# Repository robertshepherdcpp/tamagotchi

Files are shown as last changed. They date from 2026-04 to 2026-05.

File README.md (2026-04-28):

# tamagotchi
luna-tamagotchi
my second project for fallout

**what the project is:**
- a custom tamagotchi consisting of a pcb designed in kiad and a case designed in the CAD software Fusion360
what the tamagotchi consists of:
- - a 3d case + lid
  - the pcb which consists of: XIAO-ESP32-C6, buzzer, rotary encoder, 4 buttons, and a 0.96" screen.

**why i chose to make with project (the inspiration/motivation):**
- as i am still new to hardware, i thought having a tutorial as a fallback for if i got stuck would be useful (avoid endless rabbit holes hhh). also i remember using a tamagotchi when i was younger and thought it was pretty cool
- so i decided to make a tamagotchi but to personalize it, so i made it of my friend luna.
- therefore as the firmware i planned to make it have many of the same interests/personality traits as my friend
- my mum had one of these when she was younger, and I thought it would be cool to make my own version and show it to her.

**how to use my project**
- first print off etc. the pcb and case. many different providers to do this.
- then to load the firmware (found in this respository), you can:
```
download the arduino IDE, install all the relevant libraries: Adafruit SSD1306 (by Adafruit), Adafruit GFX Library (by Adafruit). then
load up the xiao-esp32-c6 board. plug the project into your computer via usb, and press port on the arduino guide. as this project doesnt have a battery built
in, in order for this project to work it has to have a usb connected to it at all times.
for more help you can refer to these two guides:
https://fallout.hackclub.com/docs/guided-projects/tamagotchi-firmware
https://wiki.seeedstudio.com/xiao_esp32c6_getting_started/
```

**how the project works**
- the project is mainly just a tamogatchi with a few little changes.
- the pet has different characteristics, hunger, happiness, energy, age, intelligence
- there are 4 main states: `nap [SJ]`, `feed luosifen [LSF]`, `climb a mountain [CLMB]`, `wildcard [WLDCRD]`.
- nap: energy increases by 15 points, intelligence increases by 10 points.
- feed: hunger increases by 10 points (means it is getting less hungry), energy increases by 5 points
- play: happiness increases by 10 points, energy decreases by 5 points
- wildcard: this is where the rotary encoder comes into play, you select a random orientation on the tamogotchi which corresponds to a number
0-19 inclusive. a random number is then selected, if you pick that number, the one below it or above it, the pets happiness is doubled! however if you
dont guess correctly, its decreased by 15%!! are you willing to risk your pets happiness?
- all values apart from age are capped in the ranges 1 to 100.
- the aim to get all values as high as possible.
- this is all done behind the scenes with the pcb, controlled by the XIAO-ESP32-C6.

**how to use it?**
- after setting up the project (with the PCB and Case etc. all set up):
- this tamagotchi is your pet, you can feed it (luosifen), let it play (climb mountains), let it take a nap, and you can also go to a section called the wildcard
- this is where you pick a random number between 1 and 18 and if you get the number or one of the adjacent numbers, your pets happiness doubles! however if not the happiness is decreased by 15%.
- your ultimate goal is to keep your pet happy, healthy etc. by keeping the 4 stats variables high (intelligence, hunger, energy and happiness)

here are some images of the project:




(there are a few components missing in this image because the STEP files for them didnt load, however shouldnt have any effect when it comes to
the actual PCB fabrication.)



estimated costs (via uploading gerber files to jlcpcb):

[link](https://cart.jlcpcb.com/quote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)

my zine:


The BOM (available in BOM.csv in this github repo):
aliexpress [link](https://www.aliexpress.com/p/shoppingcart/index.html?spm=a2g0o.tm1000056364.header.1.52471bf5lQ3z1L)

Total Cost: $27.44

the whole building process was documented on my youtube channel [here](https://www.youtube.com/@robertshepherdcpp)

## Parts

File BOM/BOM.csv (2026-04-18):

Item | Description | Quantity | Unit Price ($) | Total Price ($) | URL | Running Total ($ with Tax)
XIAO ESP32 C3 | MCU | 1 | $4.34 | $4.34 | https://www.aliexpress.us/item/3256808605622611.html | $4.34
Display | s | 1 | $2.46 | $2.46 | https://www.aliexpress.us/item/3256807544901434.html | $6.80
Headers | Headers | 1 | $1.57 | $1.57 | https://www.aliexpress.us/item/3256811506646304.html | $8.37
Buzzer | 12*9.5mm | 1 | $2.23 | $2.23 | https://www.aliexpress.us/item/3256810135642750.html | $10.60
Button | 4.5X4.5MM Button | 1 | $2.01 | $2.01 | https://www.aliexpress.us/item/3256806953793236.html | $12.61
Threaded Inserts | M3X4X5 | 1 | $2.47 | $2.47 | https://www.aliexpress.us/item/3256811754262338.html | $15.08
Screws | M3, 10mm | 1 | $1.94 | $1.94 | https://www.aliexpress.com/p/shoppingcart/index.html?spm=a2g0o.tm1000056364.header.1.52471bf5lQ3z1L | $17.02
Rotary Encoder EC11 | "20mm" | 1 | $3.12 | $3.12 | https://alishort.com/0M4I1 | $20.14
Shipping | Aliexpress | 1 | $0 | $0 | https://www.aliexpress.us/ | $20.14
PCB | JLCPCB | 1 | $4 | $4 | https://jlcpcb.com/ | $24.14
Shipping | JLCPCB | 1 | $3.30 | $3.30 | https://jlcpcb.com/ | $27.44

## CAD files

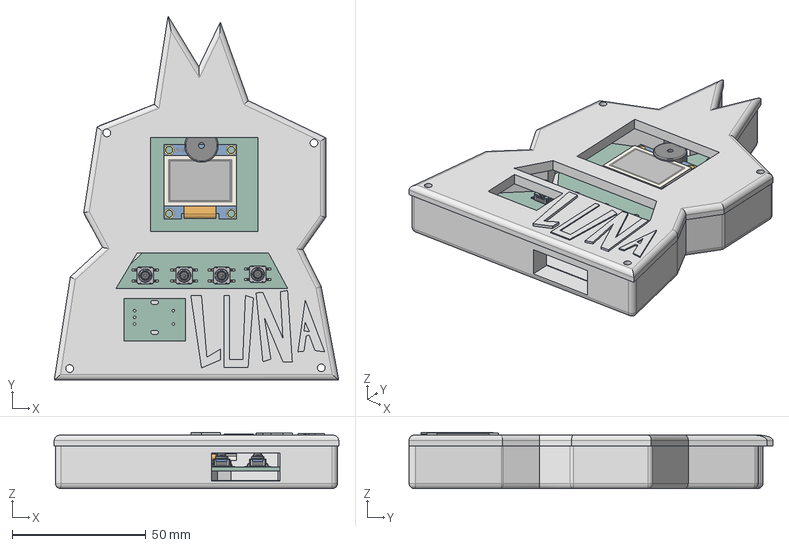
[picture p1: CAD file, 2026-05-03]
CAD/luna_2.step
106.3 x 135.9 x 21.0 mm
OLED-TH_L27.8-W27.2-P2.54_C9900033791
SW_Push_1P1T_NO_CK_KSC6xxG x 4
BUZ-TH_BD12.5-H7.0-P6.5
luna_PCB

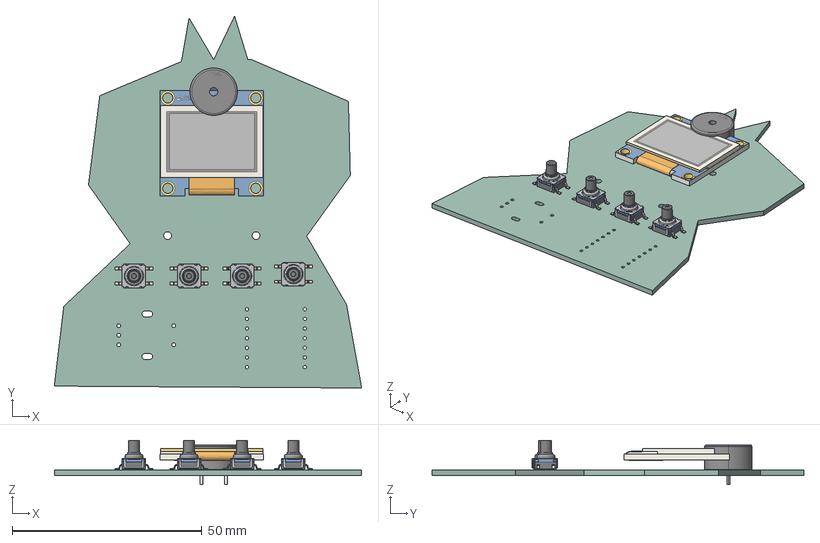
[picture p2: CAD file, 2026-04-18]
PCB/luna.step
81.0 x 98.0 x 11.7 mm
OLED-TH_L27.8-W27.2-P2.54_C9900033791
SW_Push_1P1T_NO_CK_KSC6xxG x 4
BUZ-TH_BD12.5-H7.0-P6.5
luna_PCB

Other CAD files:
CAD/luna_2.f3d

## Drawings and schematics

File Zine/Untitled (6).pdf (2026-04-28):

l

## a tamagotchi

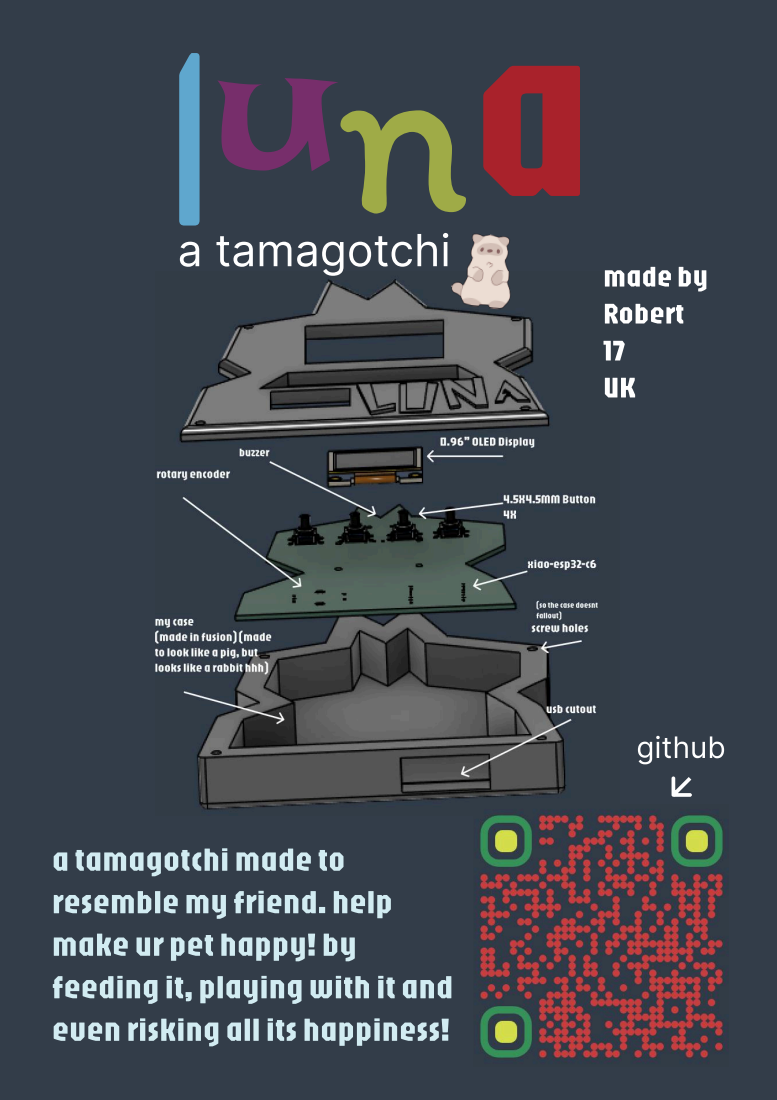
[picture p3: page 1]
una; made by Robert 17 UK; github

a tamagotchi made to
resemble my friend. help
make ur pet happy! by
feeding it, playing with it and
even risking all its happiness!

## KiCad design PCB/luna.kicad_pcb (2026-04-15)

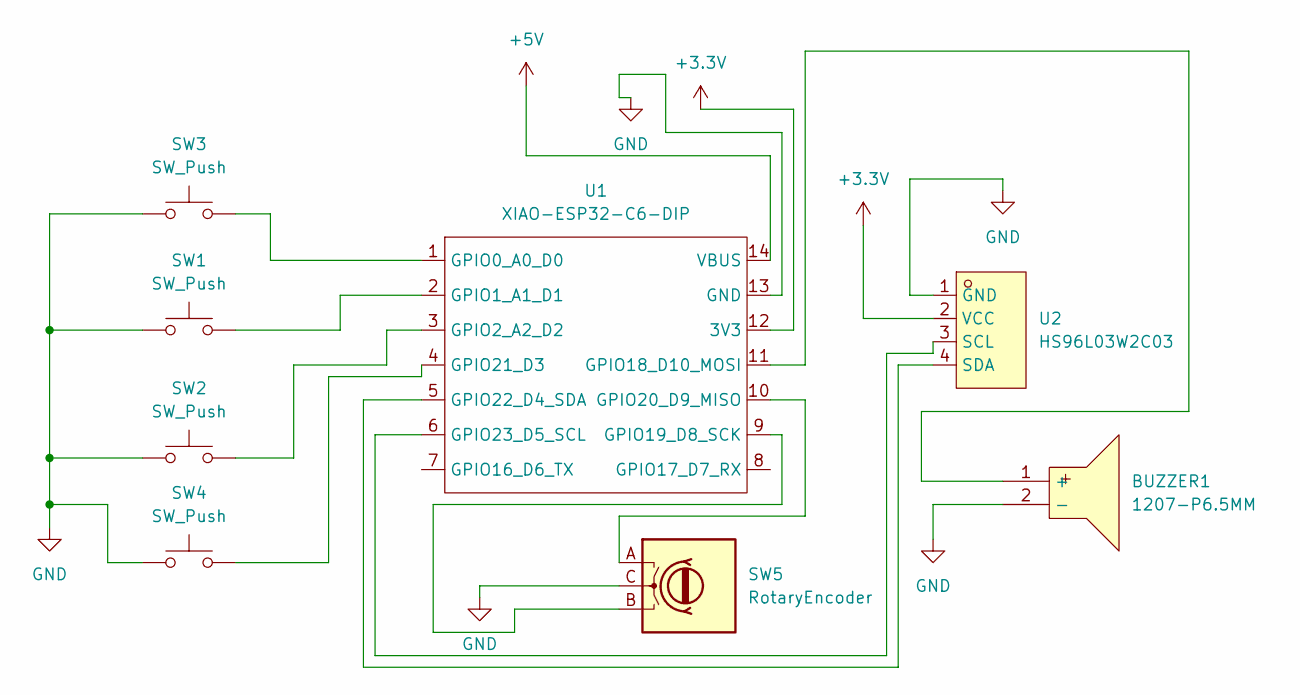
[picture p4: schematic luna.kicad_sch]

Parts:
BUZZER1: 1207-P6.5MM; BUZ-TH_BD12.5-P6.50-D1.4; MPN 1207-P6.5MM; LCSC Part C49246964
SW1, SW2, SW3, SW4: SW_Push; SW_Push_1P1T_NO_CK_KSC6xxG
SW5: RotaryEncoder; RotaryEncoder_Alps_EC11E-Switch_Vertical_H20mm
U1: XIAO-ESP32-C6-DIP
U2: HS96L03W2C03; OLED-TH_L27.8-W27.2-P2.54_C9900033791; MPN HS96L03W2C03; LCSC Part C5248080

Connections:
+3.3V: U1.12 (3V3), U2.2 (VCC)
+5V: U1.14 (VBUS)
GND: BUZZER1.2 (-), SW1.1, SW2.1, SW3.1, SW4.1, SW5.C, U1.13 (GND), U2.1 (GND)
unnamed: BUZZER1.1 (+), U1.11 (GPIO18_D10_MOSI)
unnamed: SW3.2, U1.1 (GPIO0_A0_D0)
unnamed: SW1.2, U1.2 (GPIO1_A1_D1)
unnamed: SW2.2, U1.3 (GPIO2_A2_D2)
unnamed: SW5.B, U1.9 (GPIO19_D8_SCK)
unnamed: SW5.A, U1.10 (GPIO20_D9_MISO)
unnamed: SW4.2, U1.4 (GPIO21_D3)
unnamed: U1.5 (GPIO22_D4_SDA), U2.4 (SDA)
unnamed: U1.6 (GPIO23_D5_SCL), U2.3 (SCL)

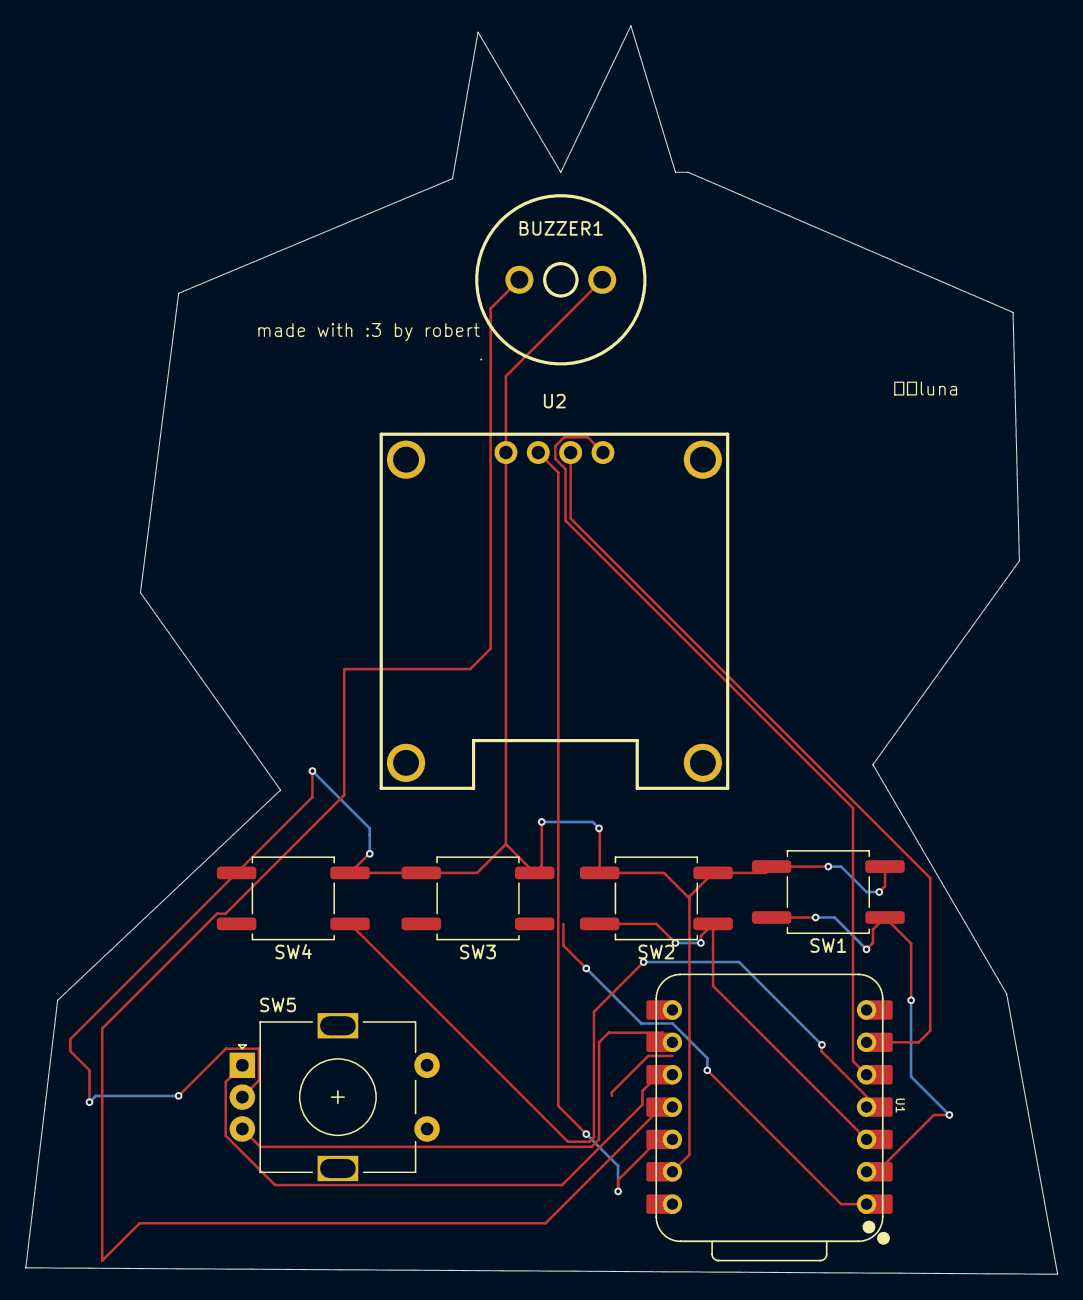
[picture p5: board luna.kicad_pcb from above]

Board: 2 copper layers, 81.0 x 98.0 mm, 8 parts (0 on the bottom side), 11 nets.

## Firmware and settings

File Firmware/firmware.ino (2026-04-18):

/*
summary of game logic:
plan for the different components
button:
1. Feed luosifen = feed (hunger)
2. Climb mountain = play (happiness, and decrease energy)
3. Nap = sleep (energy increased, intelligence increased by 1)
4. study = NEW ONE (increase intelligence by 10)

also a new stat called intelligence

for the rotary encoder - after a random amount of time on the main screen, say 5 seconds, can be taken to a wild card,
where a random number is calculated from 1 to 20, if they get the number (they can select it using the buttons)
- if they get the number, the number bellow, the number or the number above then the score is doubled!
- otherwise the score is decreased by 15% (*0.85)


*/

// buttons
#define BTN1 0
#define BTN2 1
#define BTN3 2
#define BTN4 21

//OLED display
#define SDA_PIN 22
#define SCL_PIN 23

// buzzer
#define BZR 18

// rotary encoder
#define RE_A 20
#define RE_B 19

// includes, and setting up other stuff
#include <Wire.h>
#include <Adafruit_GFX.h>
#include <Adafruit_SSD1306.h>

#define SCREEN_WIDTH 128
#define SCREEN_HEIGHT 64
#define OLED_RESET -1

Adafruit_SSD1306 display(SCREEN_WIDTH, SCREEN_HEIGHT, &Wire, OLED_RESET);

#define BTN_LEFT D0    // EAT LUOSIFEN
#define BTN_MIDDLE D1  // CLIMB A MOUNTAIN
#define BTN_RIGHT D2   // NAP
#define BTN_DOWN D3    // STUDY

#define BUZZER_PIN D10

// im not sure if this is correct, but did the same for buttons, so probably the same.
#define RotaryEncoderA D9
#define RotaryEncoderB D8

struct Pet {
  int hunger;         // 0 to 100 (0 = starving, 100 = full)
  int happiness;      // 0 to 100 (0 = miserable, 100 = ecstatic)
  int energy;         // 0 to 100 (0 = exhausted, 100 = fully rested)
  unsigned long age;  // total seconds the pet has been alive
  int intelligence;   // 0 to 100 (0 = dumb, 100 = mega brain)
};

// globals

Pet pet{};

int prev_CLK_state;  // checking if has changed, when using the rotary encoder
int count;           // measured of the rotary encoder. 1-20 (360 degrees and 18 degree increments)
int lastValue{};

enum Screen {
  SCREEN_MAIN,
  SCREEN_FEED,     // eat luosifen
  SCREEN_PLAY,     // climb mountain
  SCREEN_SLEEP,    // nap
  SCREEN_STUDY,    // study
  SCREEN_WILDCARD  // pick a random number between 1 and 4 if right .... (this is done if the user stays on the main screen for 10 seconds)
};

Screen currentScreen = SCREEN_MAIN;

void setup() {
  pinMode(BTN_LEFT, INPUT_PULLUP);
  pinMode(BTN_MIDDLE, INPUT_PULLUP);
  pinMode(BTN_RIGHT, INPUT_PULLUP);
  pinMode(BTN_DOWN, INPUT_PULLUP);

  pinMode(BUZZER_PIN, OUTPUT);

  // TODO: also do for the rotary encoder, but probably wont be the same, do some research....
  pinMode(RotaryEncoderA, INPUT);  // seems like these dont need a pullup, but idk...
  pinMode(RotaryEncoderB, INPUT);

  prev_CLK_state = digitalRead(RotaryEncoderA);

  display.begin(SSD1306_SWITCHCAPVCC, 0x3C);
  display.clearDisplay();
  display.setTextSize(1);
  display.setTextColor(SSD1306_WHITE);
  display.setCursor(0, 0);
  display.println("LUNA Init...");
  display.display();
  delay(1000);

  pet.hunger = 80;
  pet.happiness = 80;
  pet.energy = 80;
  pet.age = 0;
}

unsigned long lastUpdate = 0;

void updatePet() {
  if (millis() - lastUpdate > 5000) {  // every 5 seconds
    pet.hunger--;
    pet.happiness--;
    pet.energy--;

    if (pet.hunger < 0) pet.hunger = 0;
    if (pet.happiness < 0) pet.happiness = 0;
    if (pet.energy < 0) pet.energy = 0;

    pet.age += 5;
    lastUpdate = millis();
  }
}

unsigned long lastButtonPress = 0;

void checkButtons() {
  if (millis() - lastButtonPress < 200) return;  // debounce: ignore presses within 200ms

  if (digitalRead(BTN_LEFT) == LOW) {
    currentScreen = SCREEN_FEED;
    tone(BUZZER_PIN, 1000, 50);
    lastButtonPress = millis();
  } else if (digitalRead(BTN_MIDDLE) == LOW) {
    currentScreen = SCREEN_PLAY;
    tone(BUZZER_PIN, 1200, 50);
    lastButtonPress = millis();
  } else if (digitalRead(BTN_RIGHT) == LOW) {
    currentScreen = SCREEN_SLEEP;
    tone(BUZZER_PIN, 800, 50);
    lastButtonPress = millis();
  } else if (digitalRead(BTN_DOWN) == LOW) {  //i.e. its clicked
    currentScreen = SCREEN_WILDCARD;
    tone(BUZZER_PIN, 1400, 75);
    lastButtonPress = millis();
  }
}

void handleScreenLogic() {
  switch (currentScreen) {

    case SCREEN_FEED:
      pet.hunger += 10;
      pet.energy += 5;
      if (pet.energy > 100) pet.energy = 100;
      if (pet.hunger > 100) pet.hunger = 100;
      currentScreen = SCREEN_MAIN;
      break;

    case SCREEN_PLAY:
      pet.happiness += 10;
      pet.energy -= 5;
      if (pet.happiness > 100) pet.happiness = 100;
      if (pet.energy < 0) pet.energy = 0;
      currentScreen = SCREEN_MAIN;
      break;

    case SCREEN_SLEEP:
      pet.energy += 15;
      pet.intelligence += 10;
      if (pet.intelligence > 100) pet.intelligence = 100;
      if (pet.energy > 100) pet.energy = 100;
      currentScreen = SCREEN_MAIN;
      break;

    case SCREEN_WILDCARD:
    {
      // here we are going to check for the rotary encoder getting moved
      // CLK = A
      // DT = B

      // to check if there has been any change.
      lastValue = count;

      auto currentStateCLK = digitalRead(RotaryEncoderA);

      auto start = millis();

      while (millis() - start < 3000) {
        if (currentStateCLK != prev_CLK_state) {
          // Read the state of DT to determine rotation direction
          if (digitalRead(RotaryEncoderB) != currentStateCLK) {
            if (count == 19) {
              count = -1;  // which then gets incremented to 0.
            }
            count++;  // Clockwise rotation
          } else {
            if (count == 0) {
              count = 20;  // which then gets decremented to 19.
            }
            count--;  // Counterclockwise rotation
          }
        }
        prev_CLK_state = currentStateCLK;
      }

      // now we have got the count, we need to find a random number.
      int num = int(random(0, 20));
      // check if it is round about.
      if (count == (num - 1) || count == (num) || count == (num + 1)) {
        pet.happiness *= 2;
        if (pet.happiness > 100) {
          pet.happiness = 100;
        }
      } else {
        // they didnt get it, decrease by 15%
        pet.happiness = int(pet.happiness * 0.85);
      }
      currentScreen = SCREEN_MAIN;
    }
    break;

    case SCREEN_MAIN:
      break;  // do nothing, just display stats
  }
}

const unsigned char PROGMEM petHappy[] = {
  0b00000000, 0b00000000,
  0b00000001, 0b11110000,
  0b00000011, 0b00011000,
  0b00000110, 0b00001000,
  0b00001100, 0b00001000,
  0b00011001, 0b00100100,
  0b00010000, 0b00000100,
  0b00110000, 0b00000100,
  0b00100010, 0b00100100,
  0b00100011, 0b01100100,
  0b00100011, 0b11000100,
  0b00110000, 0b00001100,
  0b00011000, 0b00001000,
  0b00001100, 0b00011000,
  0b00000111, 0b11110000,
  0b00000000, 0b00000000
};

// Usage:
// display.drawBitmap(x, y, sprite, 16, 16, SSD1306_WHITE);

// Example: Sad face (any stat below 30)
const unsigned char PROGMEM petSad[] = {
  0b00000000, 0b00000000,
  0b00000001, 0b11110000,
  0b00000011, 0b00011000,
  0b00000110, 0b00001000,
  0b00001100, 0b00001000,
  0b00011001, 0b00100100,
  0b00010000, 0b00000100,
  0b00110000, 0b00000100,
  0b00100011, 0b11000100,
  0b00100110, 0b01100100,
  0b00100100, 0b00100100,
  0b00110000, 0b00001100,
  0b00011000, 0b00001000,
  0b00001100, 0b00011000,
  0b00000111, 0b11110000,
  0b00000000, 0b00000000
};

// Usage:
// display.drawBitmap(x, y, sprite, 16, 16, SSD1306_WHITE);

const unsigned char PROGMEM petNeutral[] = {
  0b00000000, 0b00000000,
  0b00000001, 0b11110000,
  0b00000011, 0b00011000,
  0b00000110, 0b00001000,
  0b00001100, 0b00001000,
  0b00011001, 0b00100100,
  0b00010000, 0b00000100,
  0b00110000, 0b00000100,
  0b00100000, 0b00000100,
  0b00100111, 0b11100100,
  0b00100000, 0b00000100,
  0b00110000, 0b00001100,
  0b00011000, 0b00001000,
  0b00001100, 0b00011000,
  0b00000111, 0b11110000,
  0b00000000, 0b00000000
};

//pet sleep
const unsigned char PROGMEM sprite[] = {
  0b00000000, 0b00000000,
  0b00000001, 0b11110000,
  0b00000011, 0b00011000,
  0b00000110, 0b00001000,
  0b00001100, 0b00001000,
  0b00011000, 0b00000100,
  0b00010000, 0b00000100,
  0b00110000, 0b00000100,
  0b00100000, 0b00000100,
  0b00100011, 0b11100100,
  0b00100000, 0b00000100,
  0b00110000, 0b00001100,
  0b00011000, 0b00001000,
  0b00001100, 0b00011000,
  0b00000111, 0b11110000,
  0b00000000, 0b00000000
};

// Usage:
// display.drawBitmap(x, y, sprite, 16, 16, SSD1306_WHITE);

void render() {
  display.clearDisplay();

  // Choose the right sprite based on pet stats
  const unsigned char* sprite;
  if (pet.hunger < 30 || pet.happiness < 30 || pet.energy < 30) {
    sprite = petSad;
  } else if (pet.hunger > 50 && pet.happiness > 50 && pet.energy > 50) {
    sprite = petHappy;
  } else {
    sprite = petNeutral;
  }

  // Draw the pet sprite (centered horizontally, near the top)
  display.drawBitmap(56, 2, sprite, 16, 16, SSD1306_WHITE);

  // Draw stat bars below the pet
  display.setTextSize(1);

  display.setCursor(0, 24);
  display.print("HUN ");
  drawBar(24, 24, pet.hunger);

  display.setCursor(0, 30);
  display.print("HAP ");
  drawBar(24, 30, pet.happiness);

  display.setCursor(0, 36);
  display.print("ENG ");
  drawBar(24, 36, pet.energy);

  display.setCursor(0, 42);
  display.print("INTG ");
  drawBar(24, 42, pet.intelligence);

  // should we print out the age?
  Serial.println(pet.age);  // just print it out to the console for now.

  // Button labels at the bottom
  display.setCursor(0, 56);
  display.println("[LSF] [CLMB] [SJ] [WLDCRD]");

  display.display();
}

// Draws a stat bar: empty rectangle with a filled portion based on value (0 to 100)
void drawBar(int x, int y, int value) {
  int barWidth = 100;
  int barHeight = 6;
  int fillWidth = map(value, 0, 100, 0, barWidth);

  display.drawRect(x, y, barWidth, barHeight, SSD1306_WHITE);   // outline
  display.fillRect(x, y, fillWidth, barHeight, SSD1306_WHITE);  // filled portion
}

void loop() {
  checkButtons();       // 1. Read input
  updatePet();          // 2. Update state over time
  handleScreenLogic();  // 3. Process actions
  render();             // 4. Display results
  delay(100);           // 5. Short pause
}

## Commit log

2026-04-15 add the pcb files (still need the gerber files)
    [luna.kicad_pcb, luna.kicad_sch]
2026-04-15 add the gerber files
2026-04-15 Add TODO for BOM section in README
    Added a TODO note to write the BOM section in the README.
2026-04-18 Add BOM.csv with bill of materials details
    [BOM.csv]
2026-04-18 Update README with new zine image and BOM details
    Added a new image to the zine section and updated the BOM information.
2026-04-18 Rename Gerber files.zip to PCB/Gerber files.zip
2026-04-27 Update README with new images and BOM details
    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
